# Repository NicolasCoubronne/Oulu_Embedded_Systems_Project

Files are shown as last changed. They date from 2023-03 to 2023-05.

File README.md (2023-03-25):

# Oulu_Embedded_Systems_Project

## Embedded System Project 2023, group 2

Clone :

git clone https://github.com/NicolasCoubronne/Oulu_Embedded_Systems_Project.git

Pull :

git pull

Push : 

git add *

git commit -m "name of commit"

<<<<<<< HEAD
git push origin main
=======
git push origin main
>>>>>>> 29aacac8a4f2100fd199b27751b34c95d99f8d8b

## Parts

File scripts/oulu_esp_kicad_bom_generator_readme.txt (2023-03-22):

Put oulu_esp_kicad_bom_generator.py in KICAD_INSTALL_DIR\bin\scripting\plugins

It needs to be there to correctly import some other modules.

Then afterwards in KiCAD, tools -> Generate BOM -> click plus symbol -> add the script from the dir above

Use that script to generate the BOM with correct prices and useless fields removed

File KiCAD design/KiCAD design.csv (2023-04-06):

Source: | C:\Users\tim\Documents\esp\Oulu_Embedded_Systems_Project\KiCAD design\KiCAD design.kicad_sch
Date: | 2023-04-06
Tool: | Eeschema (6.0.11)
Generator: | C:\Program Files\KiCad\6.0\bin\scripting\plugins/oulu_esp_kicad_bom_generator.py
Component Count: | 31
Collated Components:
Item | Qty | Reference(s) | Value | Price (individual, euros) | Price (total, euros) | Purchase link & datasheet
1 | 1 | Bluetooth401 | PMOD BLE | 23.38 | 23.38 | https://www.digikey.fi/en/products/detail/digilent-inc/410-359/8605090
2 | 4 | C301, C302, C303, C304 | 1uF | 0.13 | 0.52 | https://www.digikey.fi/fi/products/detail/yageo/CC0805KKX7R7BB105/2103103
3 | 1 | C401 | 0.1uF | 0.09 | 0.09 | https://www.digikey.fi/fi/products/detail/yageo/CC0805KRX7R9BB104/302874
4 | 1 | C402 | 1nF | 0.09 | 0.09 | https://www.digikey.fi/fi/products/detail/yageo/CC0805KRX7R9BB102/302861
5 | 1 | D401 | GREEN | 0.35 | 0.35 | https://www.digikey.fi/fi/products/detail/lumex-opto-components-inc/SML-LX1206GC-TR/229139
6 | 2 | D402, D403 | RED | 0.36 | 0.72 | https://www.digikey.fi/fi/products/detail/lumex-opto-components-inc/SML-LX1206IC-TR/229140
7 | 2 | J201, J204 | Conn_02x19_Odd_Even | 2.11 | 4.22 | https://www.digikey.fi/en/products/detail/sullins-connector-solutions/PPPC192LFBN-RC/810258
8 | 2 | J202, J203 | Conn_01x03_Female | 0.24 | 0.48 | https://www.digikey.fi/en/products/detail/molex/0022035035/403302?s=N4IgTCBcDa5gDAZgKxOSAugXyA
9 | 1 | J205 | JST BATTERY | 1.50 | 1.50 | https://www.digikey.fi/en/products/detail/sparkfun-electronics/PRT-10474/8258064
10 | 2 | J206, J208 | JST SENS TOF | 0.27 | 0.54 | https://www.digikey.fi/en/products/detail/assmann-wsw-components/AW-127-06-G-T/16906693
11 | 1 | J401 | Conn_02x06_Top_Bottom | 0.74 | 0.74 | https://www.digikey.fi/en/products/detail/sullins-connector-solutions/PPTC062LFBN-RC/810212
12 | 1 | LiPo_bat401 | Li-Po battery placeholder | 12.34 | 12.34 | https://hobbyking.com/en_us/turnigy-2200mah-3s-25c-lipo-pack.html
13 | 1 | LiPo_charger401 | Li-Po battery CHARGER placeholder | 14.39 | 14.39 | https://hobbyking.com/en_us/turnigy-e3-compact-2s-3s-lipo-charger-100-240v-eu-plug.html
14 | 3 | R401, R402, R403 | 330 | 0.09 | 0.27 | https://www.digikey.fi/en/products/detail/yageo/Rc0805Jr-07330RL/728311
15 | 1 | R404 | 10k | 0.09 | 0.09 | https://www.digikey.fi/en/products/detail/yageo/RC0805JR-0710KL/728241
16 | 1 | R405 | 19.1k | 0.09 | 0.09 | https://www.digikey.fi/en/products/detail/yageo/RC0805FR-0719K1L/727656
17 | 1 | SW301 | ~ | 1.05 | 1.05 | https://www.digikey.com/en/products/detail/e-switch/RR511D1121/2116256
18 | 2 | TOF1, TOF2 | SEN0245 | 13.75 | 27.50 | https://www.digikey.fi/en/products/detail/adafruit-industries-llc/3317/6569762
19 | 1 | U301 | MCP1804T | 0.94 | 0.94 | https://www.digikey.fi/en/products/detail/microchip-technology/MCP1804T-5002I-DB/2171415
20 | 1 | U302 | MIC5317 | 0.21 | 0.21 | https://www.digikey.fi/fi/products/detail/microchip-technology/MIC5317-3-3YM5-TR/5049120
21 | 1 | U401 | ACS712xLCTR-20A | 4.01 | 4.01 | https://www.digikey.fi/en/products/detail/allegro-microsystems/ACS712ELCTR-20A-T/1284594
Total Price |  |  |  |  | 93.52 | euros

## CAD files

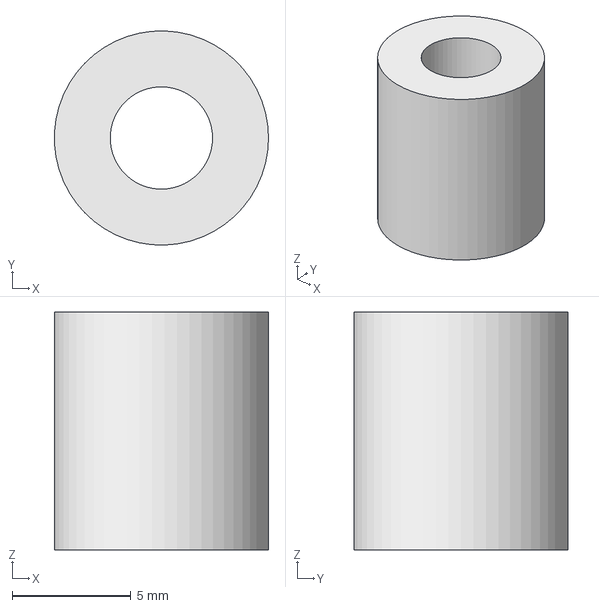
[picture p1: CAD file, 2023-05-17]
mechanical_designs/3d_printing/pcb_spacer.FCStd
8.99 x 9.00 x 10.0 mm

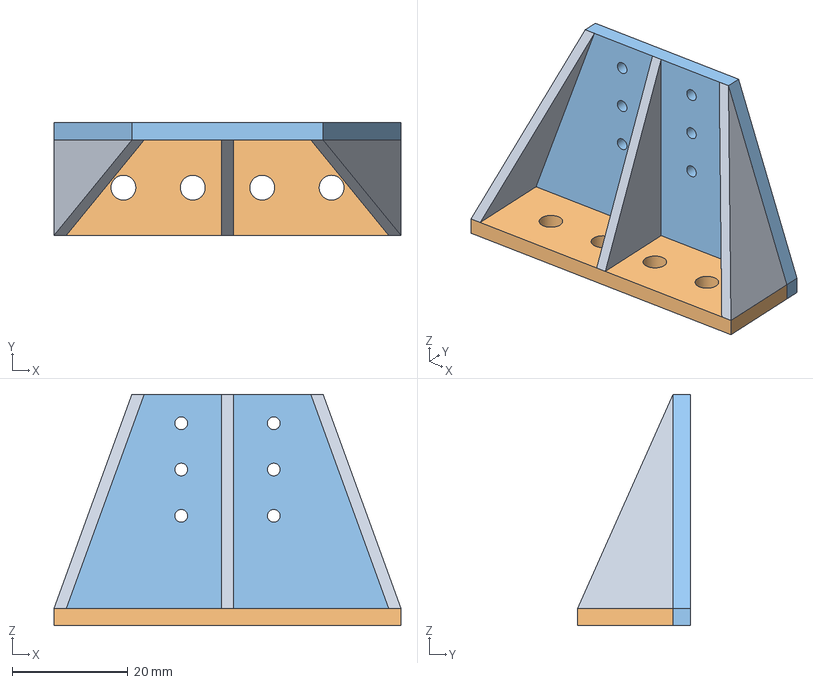
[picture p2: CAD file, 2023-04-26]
mechanical_designs/3d_printing/base_support_v2.FCStd
60.0 x 19.5 x 40.0 mm

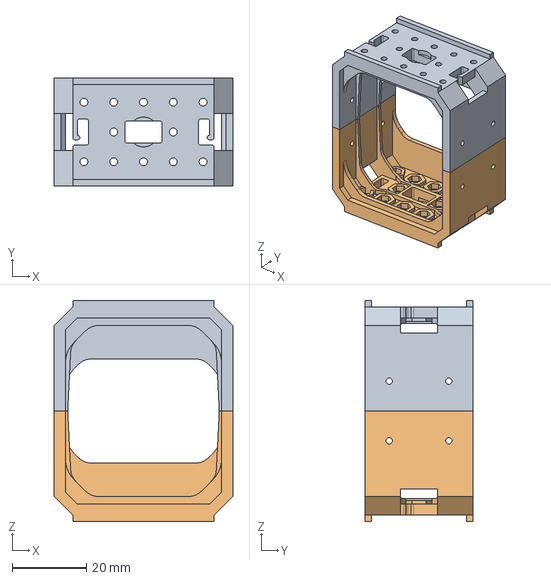
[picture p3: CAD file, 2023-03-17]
mechanical_designs/3d_printing/servo_extender.FCStd
48.0 x 29.0 x 59.4 mm
Cut (Mirror #1)

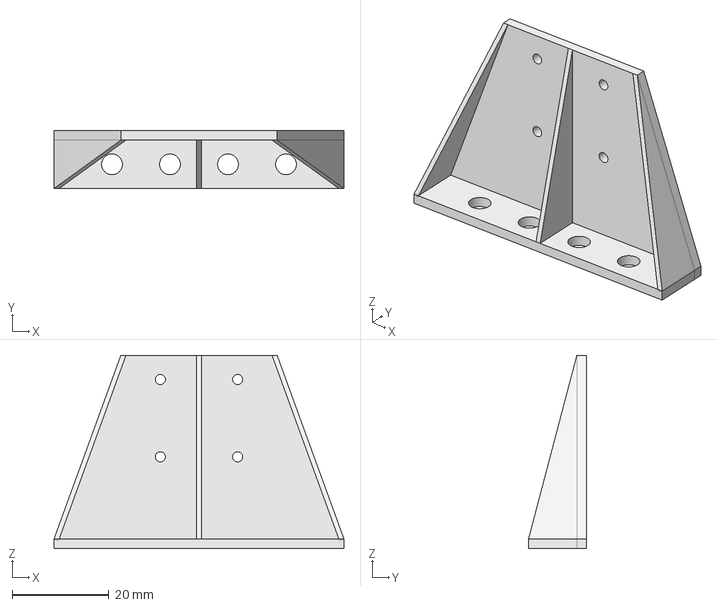
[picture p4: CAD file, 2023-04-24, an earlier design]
mechanical_designs/3d_printing/base_support_v1.FCStd
60.0 x 12.0 x 40.0 mm

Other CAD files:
mechanical_designs/3d_printing/base_support_v1.stl
mechanical_designs/3d_printing/base_support_v2.stl
mechanical_designs/3d_printing/pcb_spacer.stl
mechanical_designs/3d_printing/servo_extender.stl

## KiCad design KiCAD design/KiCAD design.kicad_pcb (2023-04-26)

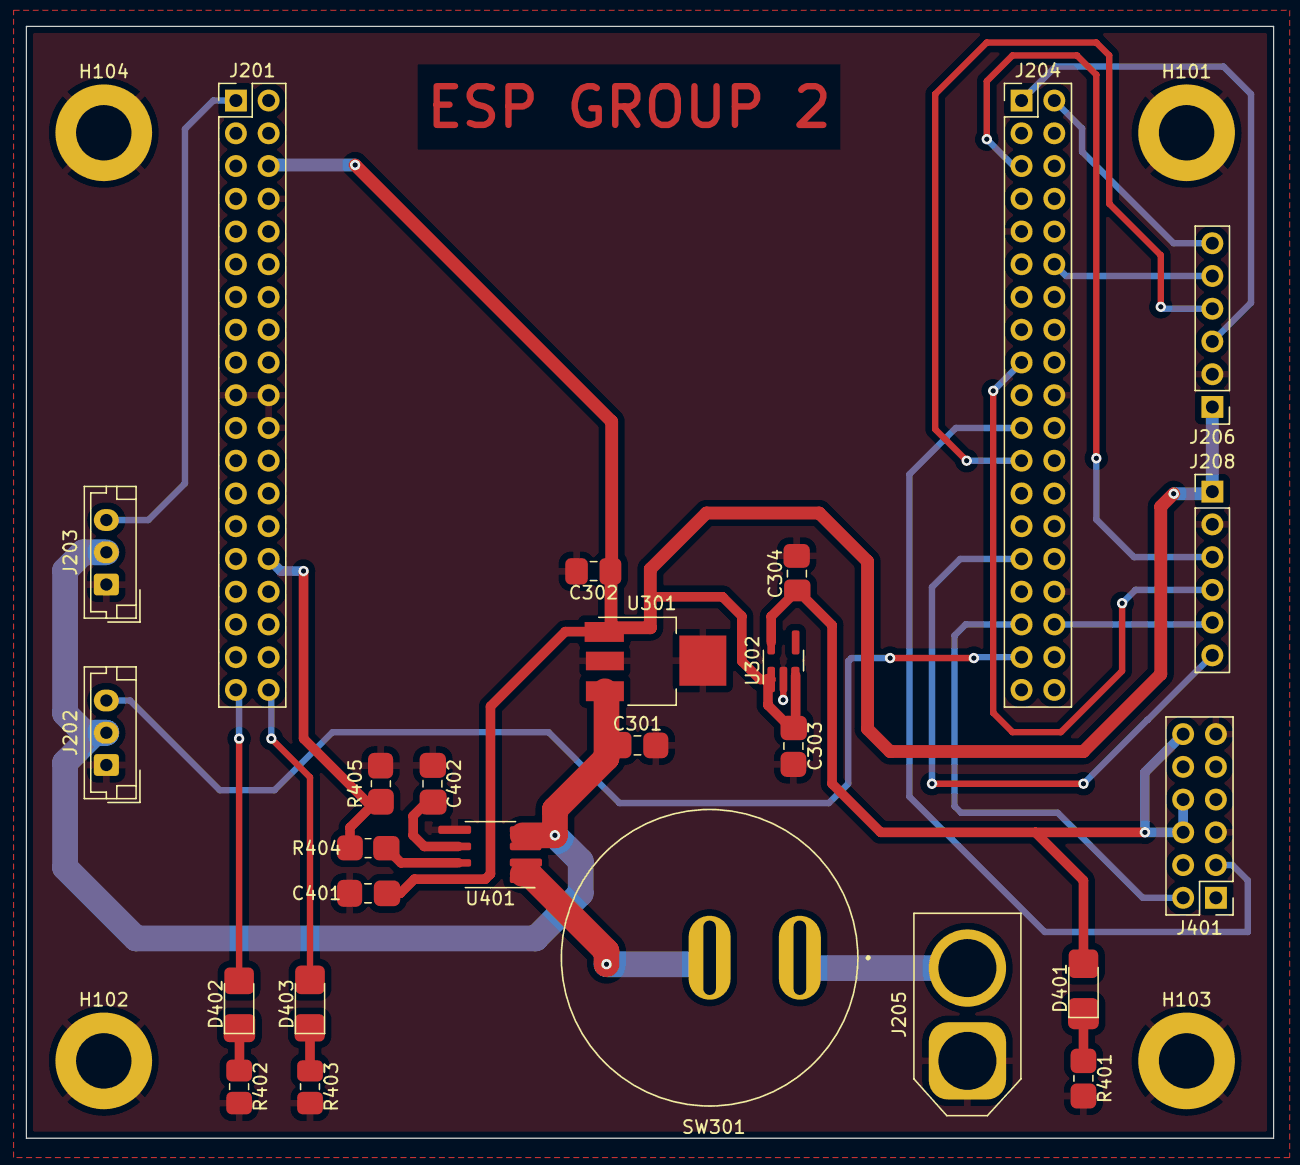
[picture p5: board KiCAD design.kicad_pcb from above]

Board: 2 copper layers, 96.8 x 86.2 mm, 30 parts (0 on the bottom side), 26 nets.

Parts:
C301, C302, C303, C304: 1uF; C_0805_2012Metric
C401: 0.1uF; C_0805_2012Metric
C402: 1nF; C_0805_2012Metric
D401: GREEN; LED_1206_3216Metric
D402, D403: RED; LED_1206_3216Metric
H101, H102, H103, H104: MountingHole_Pad; MountingHole_4.3mm_M4_DIN965_Pad
J201, J204: Conn_02x19_Odd_Even; PinHeader_2x19_P2.54mm_Vertical
J202, J203: Conn_01x03_Female; JST_EH_B3B-EH-A_1x03_P2.50mm_Vertical
J205: JST BATTERY; AMASS_XT60-M_1x02_P7.20mm_Vertical
J206: JST SENS TOF 2; PinHeader_1x06_P2.54mm_Vertical
J208: JST SENS TOF 1; PinHeader_1x06_P2.54mm_Vertical
J401: Conn_02x06_Top_Bottom; PinHeader_2x06_P2.54mm_Vertical
R401, R402, R403: 330; R_0805_2012Metric
R404: 10k; R_0805_2012Metric
R405: 19.1k; R_0805_2012Metric
SW301: E-SWITCH_RR511D1121
U301: MCP1804T; SOT-223-3_TabPin2
U302: MIC5317; SOT-23-5
U401: ACS712xLCTR-20A; SOIC-8_3.9x4.9mm_P1.27mm

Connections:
+3.3V: C304.1, D401.2 (A), J401.6, J401.8, J401.12, U302.5 (VOUT)
+5V: C302.1, C303.1, C401.2, J201.6, J206.1, J208.1, U301.1 (OUT), U302.1 (VIN), U302.3 (~SHDN), U401.8 (VCC)
+12V: C301.1, J202.2, J203.2, U301.3 (IN), U401.3 (IP-), U401.4 (IP-)
/CONNECTORS/BATT: J205.2, SW301.1 (A)
/CONNECTORS/Bluetooth_RX: J204.33, J401.2
/CONNECTORS/Bluetooth_TX: J204.21, J401.3
/CONNECTORS/CURRENT_MEASURE: J201.30, R404.2, R405.1
/CONNECTORS/LED1: D403.2 (A), J201.38
/CONNECTORS/LED2: D402.2 (A), J201.37
/CONNECTORS/TOF1_DATA_READY: J204.29, J208.6
/CONNECTORS/TOF1_SCL: J204.17, J208.4
/CONNECTORS/TOF1_SDA: J204.5, J208.3
/CONNECTORS/TOF1_XSHUT: J204.34, J208.5
/CONNECTORS/TOF2_DATA_READY: J204.2, J206.6
/CONNECTORS/TOF2_SCL: J204.23, J206.4
/CONNECTORS/TOF2_SDA: J204.1, J206.3
/CONNECTORS/TOF2_XSHUT: J204.12, J206.5
/CONNECTORS/USART_HD_ARM: J202.3, J204.35
/CONNECTORS/USART_HD_BASE: J201.1, J203.3
/ON_BOARD_COMPONENTS/IP+: SW301.2 (B), U401.1 (IP+), U401.2 (IP+)
GND: C301.2, C302.2, C303.2, C304.2, C401.1, C402.1, H101.1, H102.1, H103.1, H104.1, J201.8, J201.19, J201.20, J201.22, J202.1, J203.1, J204.9, J204.20, J204.32, J205.1, J206.2, J208.2, J401.5, J401.11, R401.2, R402.2, R403.2, R405.2, U301.2 (GND), U302.2 (GND), U401.5 (GND)
unnamed: C402.2, U401.6 (FILTER)
unnamed: D401.1 (K), R401.1
unnamed: D402.1 (K), R402.1
unnamed: D403.1 (K), R403.1
unnamed: R404.1, U401.7 (VIOUT)

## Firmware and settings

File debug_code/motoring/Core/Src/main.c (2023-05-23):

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
/* Includes ------------------------------------------------------------------*/
#include "main.h"

/* USER CODE BEGIN Includes */
#include <stdio.h>
#include <stdlib.h>
#include <inttypes.h>

#include "demos.h"
#include "esp_ax12a.h"
#include "esp_arm.h"
#include "esp_fsm.h"
#include "util.h"
/* USER CODE END Includes */

ADC_HandleTypeDef hadc1;

I2C_HandleTypeDef hi2c1;
I2C_HandleTypeDef hi2c3;

TIM_HandleTypeDef htim2;

UART_HandleTypeDef huart4;
UART_HandleTypeDef huart1;
UART_HandleTypeDef huart2;
DMA_HandleTypeDef hdma_usart1_rx;

/* USER CODE BEGIN PV */
uint8_t buf_RX[Size];
uint8_t buf_TX[Size];

/* USER CODE END PV */

void SystemClock_Config(void);
static void MX_GPIO_Init(void);
static void MX_DMA_Init(void);
static void MX_USART2_UART_Init(void);
static void MX_UART4_Init(void);
static void MX_I2C1_Init(void);
static void MX_USART1_UART_Init(void);
static void MX_TIM2_Init(void);
static void MX_I2C3_Init(void);
static void MX_ADC1_Init(void);
/* USER CODE BEGIN 0 */
int _write(int file, char *ptr, int len)

{   int DataIdx;

for(DataIdx = 0; DataIdx < len; DataIdx ++)

{
	ITM_SendChar(*ptr ++);
}

return len;

}


/* USER CODE END 0 */

/**
  * @brief  The application entry point.
  * @retval int
  */
int main(void)
{
  /* MCU Configuration--------------------------------------------------------*/

  /* Reset of all peripherals, Initializes the Flash interface and the Systick. */
  HAL_Init();

  /* Configure the system clock */
  SystemClock_Config();

  /* Initialize all configured peripherals */
  MX_GPIO_Init();
  MX_DMA_Init();
  MX_USART2_UART_Init();
  MX_UART4_Init();
  MX_I2C1_Init();
  MX_USART1_UART_Init();
  MX_TIM2_Init();
  MX_I2C3_Init();
  MX_ADC1_Init();
  /* USER CODE BEGIN 2 */
	ax_init(&huart4, NULL);

	//Start Bluetooth usart via DMA
	HAL_UART_Transmit(&huart1, (uint8_t*)"STM -> PMOD \r\n", sizeof("STM -> PMOD \r\n"), HAL_MAX_DELAY);
	HAL_UART_Receive_DMA (&huart1, buf_RX, 9);

	HAL_TIM_Base_Start_IT(&htim2);

	// Start main functionality (state machine)
	arm_start_sm();

  /* USER CODE END 2 */

  /* Infinite loop */
  /* USER CODE BEGIN WHILE */

	while (1)
	{
    /* USER CODE END WHILE */

    /* USER CODE BEGIN 3 */

	}
  /* USER CODE END 3 */
}

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


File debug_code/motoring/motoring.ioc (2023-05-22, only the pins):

Mcu.UserName=STM32F446RETx
PA1.Signal=ADCx_IN1
PA10.Signal=USART1_RX
PA12.GPIO_Label=TOF2_XSHUT
PA12.Signal=GPIO_Output
PA13.GPIO_Label=TMS
PA13.Signal=SYS_JTMS-SWDIO
PA14.GPIO_Label=TCK
PA14.Signal=SYS_JTCK-SWCLK
PA2.GPIO_Label=USART_TX
PA2.Signal=USART2_TX
PA3.GPIO_Label=USART_RX
PA3.Signal=USART2_RX
PA5.GPIO_Label=LD2_GREEN
PA5.Signal=GPIO_Output
PA8.Signal=I2C3_SCL
PA9.Signal=USART1_TX
PB3.GPIO_Label=SWO
PB3.Signal=SYS_JTDO-SWO
PB5.GPIO_Label=TOF1_IN
PB5.Signal=GPXTI5
PB6.Signal=I2C1_SCL
PB9.Signal=I2C1_SDA
PC0.GPIO_Label=LED_EXT_2
PC0.Signal=GPIO_Output
PC10.Signal=UART4_TX
PC13.GPIO_Label=B1 [Blue PushButton]
PC13.Signal=GPXTI13
PC14-OSC32_IN.Signal=RCC_OSC32_IN
PC15-OSC32_OUT.Signal=RCC_OSC32_OUT
PC3.GPIO_Label=LED_EXT_1
PC3.Signal=GPIO_Output
PC4.GPIO_Label=TOF1_XSHUT
PC4.Signal=GPIO_Output
PC8.GPIO_Label=TOF2_IN
PC8.Signal=GPXTI8
PC9.Signal=I2C3_SDA
PH0-OSC_IN.Signal=RCC_OSC_IN
PH1-OSC_OUT.Signal=RCC_OSC_OUT

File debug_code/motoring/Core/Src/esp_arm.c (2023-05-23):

/*
 * esp_arm.c
 *
 *  Created on: Apr 26, 2023
 *      Author: Jussi Virtanen
 *
 *  High-level functions for arm control
 */

#include <math.h>
#include <stdbool.h>
#include <stdio.h>
#include <stdlib.h>

#include "stm32f4xx_hal.h"

#include "esp_arm.h"


/* Convert radians to ax servo angle units
 * angle: angle in radians
 *
 * returns: angle in servo angle units
 */
unsigned int rad_to_ax(double angle)
{
	double ax_360 = 1023.0 / 300.0 * 360.0;
	return (unsigned int)(ax_360 * (angle/(2.0*M_PI)));
}

/* Get arm rotations from object distance (pythagoras + law of cosines)
 * https://en.wikipedia.org/wiki/Law_of_cosines
 *
 * angle_base_joint: base join rotation
 * angle_middle_joint: middle joint rotation
 * angle_claw_joint: claw joint rotation
 *
 * returns:
 * 	0 on success
 * 	1 if the distance is too long (arm can't extend that far)
 * 	-1 if the distance is too short (arm can't retract that close)
 */
int arm_angles_from_dist(unsigned int distance,
		unsigned int *angle_base_joint, unsigned int *angle_middle_joint, unsigned int *angle_claw_joint)
{
	/* Calculations in rads and millimeters,
	 * return values in raw servo angles
	 */
	double angle_base_joint_rad, angle_middle_joint_rad, angle_claw_joint_rad;
	double height_offset;
	double base_offset_angle, claw_offset_angle;
	double arm_len_from_base = 154.0; // a in law of cosines
	double arm_len_from_joint = 140.0; // b in law of cosines
	double max_distance;
	/* Need some height offset, basically a good estimation could be:
	 * base height - claw height + object height
	 */
	height_offset = -40.0;

	max_distance = sqrt(pow(arm_len_from_base +arm_len_from_joint,2) -pow(height_offset,2));
	if(distance >= max_distance) {
		return 1;
	}

	double dist = sqrt(pow((double)distance, 2.0) + pow(height_offset, 2.0)); // c in law of cosines

	// beta in law of cosines
	angle_base_joint_rad = acos((pow(arm_len_from_base, 2.0) + pow(dist, 2.0) - pow(arm_len_from_joint, 2.0)) / (2.0 * arm_len_from_base * dist));
	// gamma in law of cosines
	angle_middle_joint_rad = acos((pow(arm_len_from_base, 2.0) + pow(arm_len_from_joint, 2.0) - pow(dist, 2.0)) / (2.0 * arm_len_from_base * arm_len_from_joint));
	// alpha in law of cosines
	angle_claw_joint_rad = M_PI - angle_base_joint_rad - angle_middle_joint_rad;

	// Servo angles will need to be offset due to height offset
	if (height_offset < 0.0) {
		base_offset_angle = -(M_PI/2.0 - atan(dist / -height_offset));
		claw_offset_angle = -(atan(-height_offset / dist));
	} else if (height_offset > 0.0) {
		base_offset_angle = atan(height_offset / dist);
		claw_offset_angle = M_PI/2.0 - atan(dist / height_offset);
	} else {
		base_offset_angle = claw_offset_angle = 0.0;
	}
	//printf("base offset: %.2f, claw offset: %.2f\n", base_offset_angle, claw_offset_angle);

	*angle_base_joint = 512 + rad_to_ax(M_PI/2.0 - angle_base_joint_rad - base_offset_angle);
	*angle_middle_joint = 512 + rad_to_ax(M_PI - angle_middle_joint_rad);
	*angle_claw_joint = 512 + rad_to_ax(angle_claw_joint_rad - claw_offset_angle);

	return 0;
}

/* Get offset angle of base rotation based on the required offset distance
 * Needed since the angle differs based on distance
 *
 * distance: required offset distance (roughly along the tangent of the circle movement of the base)
 * claw_offset: sideways offset required by the claw (in open position it's not perfectly centered)
 *
 * returns: the offset angle required for the base rotation
 */
unsigned int offset_base_angle(unsigned int distance, double claw_offset)
{
	double offset_angle;

	offset_angle = atan(claw_offset/distance);
	return rad_to_ax(offset_angle);
}

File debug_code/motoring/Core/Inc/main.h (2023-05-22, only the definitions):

#define B1_Pin GPIO_PIN_13
#define B1_GPIO_Port GPIOC
#define LED_EXT_2_Pin GPIO_PIN_0
#define LED_EXT_2_GPIO_Port GPIOC
#define LED_EXT_1_Pin GPIO_PIN_3
#define LED_EXT_1_GPIO_Port GPIOC
#define USART_TX_Pin GPIO_PIN_2
#define USART_TX_GPIO_Port GPIOA
#define USART_RX_Pin GPIO_PIN_3
#define USART_RX_GPIO_Port GPIOA
#define LD2_GREEN_Pin GPIO_PIN_5
#define LD2_GREEN_GPIO_Port GPIOA
#define TOF1_XSHUT_Pin GPIO_PIN_4
#define TOF1_XSHUT_GPIO_Port GPIOC
#define TOF2_IN_Pin GPIO_PIN_8
#define TOF2_IN_GPIO_Port GPIOC
#define TOF2_XSHUT_Pin GPIO_PIN_12
#define TOF2_XSHUT_GPIO_Port GPIOA
#define TMS_Pin GPIO_PIN_13
#define TMS_GPIO_Port GPIOA
#define TCK_Pin GPIO_PIN_14
#define TCK_GPIO_Port GPIOA
#define SWO_Pin GPIO_PIN_3
#define SWO_GPIO_Port GPIOB
#define TOF1_IN_Pin GPIO_PIN_5
#define TOF1_IN_GPIO_Port GPIOB
#define Size 50

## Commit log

2023-03-07 Sheets and connectors
    [KiCAD design.kicad_sch, connectors.kicad_sch, on_board_components.kicad_sch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]
2023-03-14 finished conectors / sensors / converters
    [KiCAD design.kicad_sch, connectors.kicad_sch, on_board_components.kicad_sch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]
2023-03-14 labeling and add of components. STM32 pin selected
    [KiCAD design.kicad_sch, connectors.kicad_sch, on_board_components.kicad_sch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]
2023-03-15 servo extender piece (freecad + stl files)
    [servo_extender.FCStd, servo_extender.stl]
2023-03-15 dont track backups and autosaves (they are different per system, will add changes even if you dont change anything and not needed in version control)
2023-03-17 correction pin bluetooth
    [connectors.kicad_sch, on_board_components.kicad_sch, power_supply.kicad_sch]
2023-03-17 correction of errors
    [KiCAD design.kicad_sch, connectors.kicad_sch, on_board_components.kicad_sch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]
2023-03-17 add of footprint and nucleo as a reference
    [KiCAD design.kicad_sch, connectors.kicad_sch, on_board_components.kicad_sch]
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2023-03-17 add BLUETOOTH_*X labels to bluetooth module
    [connectors.kicad_sch]
2023-03-17 voltage divider for current sensor
    [KiCAD design.kicad_sch, on_board_components.kicad_sch]
2023-03-19 add purchase location (field PurchaseLoc) and price (field Price) to some main components, adding rest later
    [KiCAD design.kicad_sch, on_board_components.kicad_sch, power_supply.kicad_sch]
2023-03-20 added PurchaseLoc and Price to most of the main components, leds, resistors, capacitors, switch, bluetooth missing
    [KiCAD design.kicad_sch, connectors.kicad_sch, ext_components.kicad_sch]
2023-03-20 Added LEDs
    [KiCAD design.kicad_sch, connectors.kicad_sch, on_board_components.kicad_sch]
2023-03-21 dont track #auto_saved_files# cause it keeps getting added and deleted, that file is deleted when kicad closes
2023-03-21 add some comments, connector for battery, bluetooth (is now the PMOD BLE from digikey)
    [KiCAD design.kicad_sch, connectors.kicad_sch, ext_components.kicad_sch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]
2023-03-21 add connector for Pmod BLE (HC05 connector still left)
    [KiCAD design.kicad_sch, connectors.kicad_sch]
2023-03-21 add comment for bluetooth connectors
    [connectors.kicad_sch]
2023-03-21 Added capacitors and resistors
    [KiCAD design.kicad_sch, on_board_components.kicad_sch, power_supply.kicad_sch]
2023-03-21 add link to switch and 1k resistor
    [KiCAD design.kicad_sch, ext_components.kicad_sch, on_board_components.kicad_sch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]
2023-03-21 remove hc05 connector
    [KiCAD design.kicad_sch, connectors.kicad_sch]
2023-03-22 use . as decimal separator
    [KiCAD design.kicad_sch, connectors.kicad_sch, on_board_components.kicad_sch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]
2023-03-22 use individual prices
    [ext_components.kicad_sch]
2023-03-22 better bom export script (check readme)
2023-03-22 Fixed info of 3 resistors in LED sheet
    [KiCAD design.kicad_sch, on_board_components.kicad_sch]
2023-03-23 current sensor VCC should be 5V
    [KiCAD design.kicad_sch, on_board_components.kicad_sch]
2023-03-23 10x larger resistors for voltage divider
    [KiCAD design.kicad_sch, on_board_components.kicad_sch]
2023-03-23 change led resistors to 330 ohm
    [KiCAD design.kicad_sch, on_board_components.kicad_sch]
2023-03-23 change voltage dividor resistors to larger dimensions
    [on_board_components.kicad_sch]
2023-03-25 more comments (no changes in functionality)
    [connectors.kicad_sch, ext_components.kicad_sch, on_board_components.kicad_sch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]
2023-03-25 restructure mechanical cad design dirs
    [servo_extender.FCStd, servo_extender.stl]
2023-03-28 comment about nucleo board in main sheet
    [KiCAD design.kicad_sch]
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2023-04-03 change in nucleo pin
    [KiCAD design.csv, KiCAD design.kicad_pcb, KiCAD design.kicad_sch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]
2023-04-04 fixed 3.3 voltage reg
    [power_supply.kicad_sch]
2023-04-04 exclude mounting holes from BOM
    [KiCAD design.kicad_sch]
2023-04-04 update BOM
    [KiCAD design.csv]
2023-04-04 set same value for TOF sensor connectors to group them in BOM
    [KiCAD design.csv, KiCAD design.kicad_sch, connectors.kicad_sch]
2023-04-04 update lipo battery to something in stock
    [KiCAD design.csv, ext_components.kicad_sch]
2023-04-04 change TOF sensor to one in stock (still VL53L0X, same pins)
    [KiCAD design.csv, ext_components.kicad_sch]
2023-04-05 Added datasheets for TOF sensors
    [ext_components.kicad_sch]
2023-04-05 end PCB
    [KiCAD design.csv, KiCAD design.kicad_pcb, KiCAD design.kicad_sch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]
2023-04-06 Revert "merge?"
    This reverts commit 9507821d8c903603659f1e6f71c2fe75c77c06b3, reversing
    changes made to cc7a5d21546560b2c88e49b90c103b2912c9bd5f.
    [main.c, motoring.ioc]
2023-04-06 fix reg 2.8->3.3
    [power_supply.kicad_sch]
2023-04-06 remove mounting holse from bom
    [KiCAD design.kicad_sch]
2023-04-06 tof sensor values and lipo bat
    [KiCAD design.kicad_sch, connectors.kicad_sch, ext_components.kicad_sch]
2023-04-06 tof sensor update
    [ext_components.kicad_sch]
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2023-04-08 highlight that reset is actually factory reset
    [esp_ax12a.c]
2023-04-14 KiCAD widening of copper pads
    [KiCAD design-B_Cu.gbr, KiCAD design-B_Mask.gbr, KiCAD design-B_Paste.gbr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]
2023-04-14 fix byte order and initialization variable scope
    [esp_ax12a.c]
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2023-04-21 demo 2 + fix blocked move
    [demos.c, esp_ax12a.c, main.c]
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2023-04-21 Modified PCB
    [KiCAD design-B_Cu.gbr, KiCAD design-B_Mask.gbr, KiCAD design-B_Paste.gbr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]
2023-04-24 base support frame cad v1
    [base_frame.FCStd, base_frame.stl]
2023-04-26 rename base support cad
    [base_support_v1.FCStd, base_support_v1.stl]
2023-04-26 thicker & proper width base support
    [base_support_v2.FCStd, base_support_v2.stl]
2023-04-26 Updated PCB and GRB files
    [KiCAD design-B_Cu.gbr, KiCAD design-B_Mask.gbr, KiCAD design-B_Silkscreen.gbr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]
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2023-04-26 increase support width + add holes
    [base_support_v2.FCStd, base_support_v2.stl]
2023-04-26 add base and claw angles offset, caused by height offset
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2023-05-17 bluetooth abstraction and offset fixes
    [esp_arm.c, esp_fsm.c]
2023-05-17 more bt messages, template for operational led usage
2023-05-17 make uart send/recv return something if success/fail
    [esp_ax12a.c]
2023-05-17 error led and current draw templates
    [esp_fsm.c]
2023-05-17 pcb spacer
    [pcb_spacer.FCStd, pcb_spacer.stl]
2023-05-17 fix width of spacer
    [pcb_spacer.FCStd, pcb_spacer.stl]
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

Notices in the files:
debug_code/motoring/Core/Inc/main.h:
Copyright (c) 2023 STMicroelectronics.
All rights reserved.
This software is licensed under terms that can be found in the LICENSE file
